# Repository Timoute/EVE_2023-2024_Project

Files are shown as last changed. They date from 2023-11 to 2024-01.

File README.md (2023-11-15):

# Cahier des charges Gants 

## Objectif General
- Contrôle de robot
    - Mouvement
        - Mecanique
        - " peau artificiel "
    - Contraction Muscle
    - Orientation de la main
    - Contact des doigts
    - Haptic feedback (potentiometre)
## Pour qui ?
Doit pouvoir être utilisé par une personne sans handicape 

## Présentation du projet
Objectif général : Contrôler un robot avec un gant 
Objectifs spécifiques :
- Feedback
- Réception des signaux musculaires 
- Retour sur l’orientation - position du robot
- Piloter la main avec le gant ou avoir des actions spécifiques pour chaque mouvement fait avec le gant. 
    
## Description des besoin
Besoins fonctionnels :  
- feedback réception des signaux musculaires 
- retour sur l’orientation 
- position du robot 
- piloter la main avec le gant ou avoir des actions spécifiques pour chaque mouvement fait avec le gant. 
                        
Besoins non fonctionnels : ergonomie, sécurité 

## Contraintes
Contraintes techniques : ROS, Python, C, Arduino IDE, Velostat

Contraintes budgétaires : 

Contraintes temporelles : Janvier 2024.

## Spécifications détaillées
Architecture : décrivez la structure générale du projet.

Interfaces : Cube IDE, VS Code, ROS

Bases de données : décrivez les besoins en matière de stockage et de gestion des données.

## Critères d'acceptation
- Énumérez les conditions qui doivent être remplies pour que le projet soit considéré comme réussi :
- Avoir un gant fonctionnel et ergonomique
- Acquérir des signaux en fonctions de différentes actions de la main ( mouvement des doigts, contraction des muscles, orientation de la main…)
- Avoir une communication stable 

## Liste des capteurs
- Electromyogram :
    - https://www.gotronic.fr/art-capteur-emg-sen0240-27861.htm
    - https://eu.robotshop.com/fr/products/electromyography-emg-sensor
    - https://www.mouser.fr/ProductDetail/SparkFun/DEV-18425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
    - https://www.gotronic.fr/art-capteur-pour-muscle-myoware-2-0-36900.htm
- Gyroscope, accélerometre, magnétomètre, capteur d'orientation : sans PCB : https://www.mouser.fr/ProductDetail/TDK-InvenSense/MPU-9250?qs=u4fy%2FsgLU9OhGjFkQSZssA%3D%3D
  avec PCB : https://www.amazon.fr/9250-Module-Acc%C3%A9l%C3%A9rom%C3%A8tre-Gyroscope-magn%C3%A9tom%C3%A8tre-Raspberry/dp/B01M74J70A
- Velostat(artificial skin): to capture pressure, twist
- Pressure sensor: to capture the contact between two fingers: https://www.gotronic.fr/art-capteur-de-force-fsr01-11552.htm
- Potentiometer: to capture finger bending
    Potentiometre linéaire x5: https://www.mouser.fr/ProductDetail/Bourns/PTA2043-2015CIB203?qs=AQlKX63v8RsiU3Md8%2FQpDw%3D%3D

- INSPIRATION
- https://www.youtube.com/watch?v=xNSRmXKSI_4
- https://fr.farnell.com/adafruit-industries/1361/accessory-type-conductive-sheet/dp/2419170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|pcrid||plid||kword||match||slid||product|2419170|pgrid||ptaid||&CMP=KNC-GFR-GEN-SHOPPING-Catch-All-Geo-Split-Control-12-July-23&gross_price=true

  video : https://www.youtube.com/watch?v=nHVNF83Se9k

Pourquoi celui la ? 

Pour mettre une image : 
name

https://github.com/someone-eng/LeapMotion-remote-controlling-robot-hand

MYOWare
https://cdn.sparkfun.com/assets/learn_tutorials/1/9/5/6/MyoWare_v2_QuickStartGuide.pdf
https://github.com/sparkfun/SparkFun_MyoWare_Code_Examples
https://microcontrollerslab.com/force-sensor-fsr-arduino-tutorial/

## To Order
- STM32 : https://www.mouser.fr/ProductDetail/STMicroelectronics/STM32G474RET6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

### RS Component

### Wurth Elektronik

### Mouser Electronics

# Base de Données pour IA
Fait avec le Leap Motion
https://www.kaggle.com/datasets/gti-upm/leapgestrecog/

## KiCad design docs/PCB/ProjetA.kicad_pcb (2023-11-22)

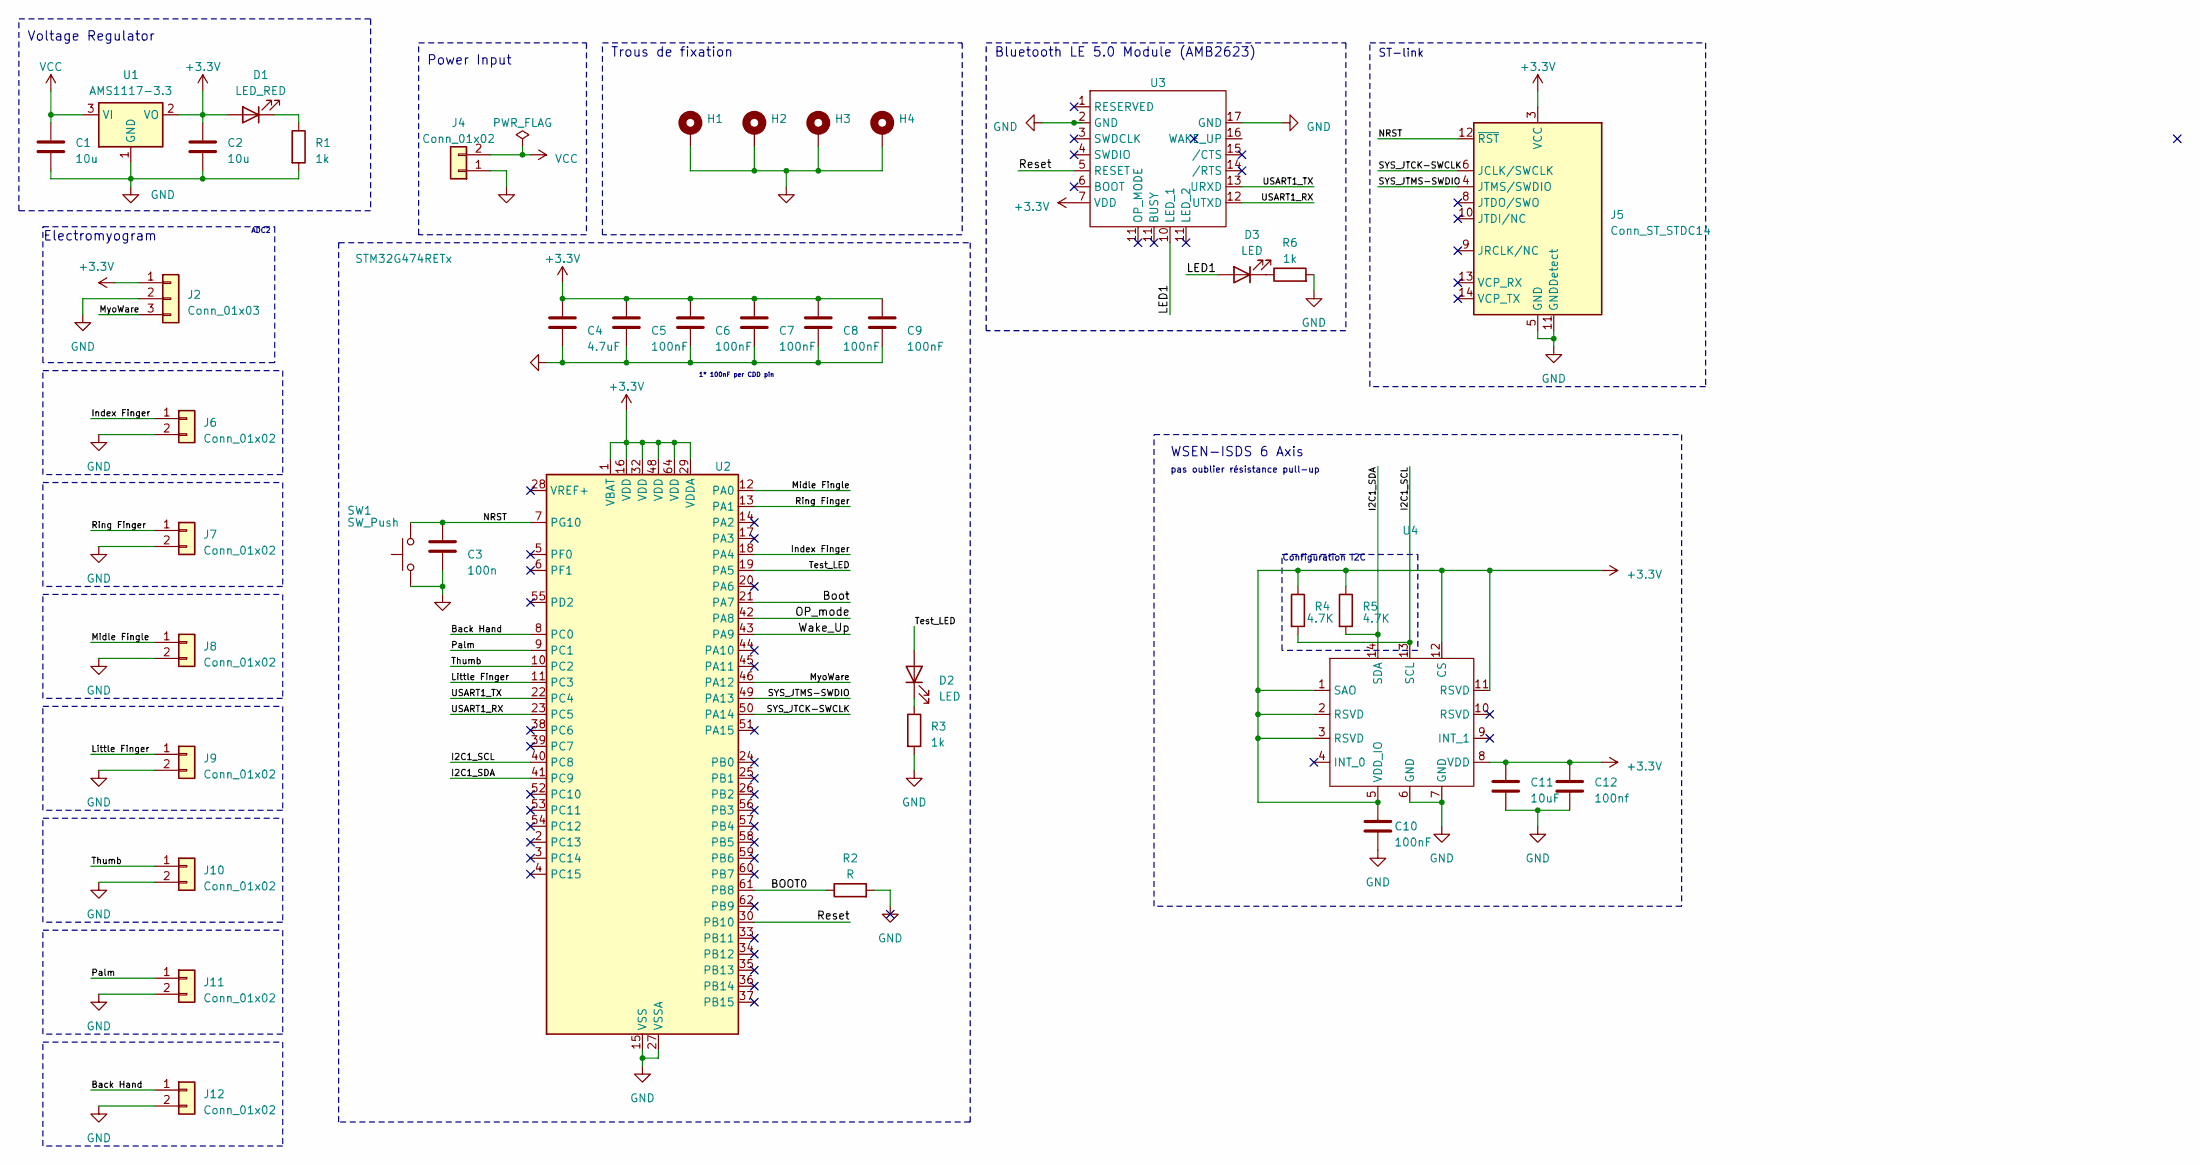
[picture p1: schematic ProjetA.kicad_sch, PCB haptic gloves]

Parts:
C1, C2: 10u; C_0603_1608Metric_Pad1.08x0.95mm_HandSolder
C3: 100n; C_0603_1608Metric_Pad1.08x0.95mm_HandSolder
C4: 4.7uF; C_0603_1608Metric_Pad1.08x0.95mm_HandSolder
C5, C6, C7, C8, C9, C10: 100nF; C_0603_1608Metric_Pad1.08x0.95mm_HandSolder
C11: 10uF; C_0603_1608Metric_Pad1.08x0.95mm_HandSolder
C12: 100nf; C_0603_1608Metric_Pad1.08x0.95mm_HandSolder
D1: LED_RED; LED_0603_1608Metric_Pad1.05x0.95mm_HandSolder
D2, D3: LED; LED_0603_1608Metric_Pad1.05x0.95mm_HandSolder
H1, H2, H3, H4: MountingHole_Pad; MountingHole_2.7mm_Pad_Via
J2: Conn_01x03; JST_XH_B3B-XH-A_1x03_P2.50mm_Vertical
J4: Conn_01x02; JST_XH_B2B-XH-A_1x02_P2.50mm_Vertical
J5: Conn_ST_STDC14; PinHeader_2x07_P1.27mm_Vertical_SMD
J6, J7, J8, J9, J10, J11, J12: Conn_01x02; JST_XH_S2B-XH-A_1x02_P2.50mm_Horizontal
R1, R3, R6: 1k; R_1206_3216Metric_Pad1.30x1.75mm_HandSolder
R2: R; R_1206_3216Metric_Pad1.30x1.75mm_HandSolder
R4, R5: 4.7K; R_1206_3216Metric_Pad1.30x1.75mm_HandSolder
SW1: SW_Push; SW_SPST_B3U-1000P
U1: AMS1117-3.3; SOT-223-3_TabPin2
U2: STM32G474RETx; LQFP-64_10x10mm_P0.5mm
U3: Proteus-II (Bluetooth)
U4: WSEN-ISDS 6 Axis IMU

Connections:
+3.3V: C2.2, C4.1, C5.1, C6.1, C7.1, C8.1, C9.1, C10.1, C11.1, C12.1, D1.2 (A), J2.1, J5.3 (VCC), R4.1, R5.1, U1.2 (VO), U2.1 (VBAT), U2.16 (VDD), U2.29 (VDDA), U2.32 (VDD), U2.48 (VDD), U2.64 (VDD), U3.7 (VDD), U4.1 (SAO), U4.2 (RSVD), U4.3 (RSVD), U4.5 (VDD_IO), U4.8 (VDD), U4.11 (RSVD), U4.12 (CS)
/BOOT0: R2.1, U2.61 (PB8)
/Back Hand: J12.1, U2.8 (PC0)
/Boot: U2.21 (PA7)
/I2C1_SCL: R4.2, U2.40 (PC8), U4.13 (SCL)
/I2C1_SDA: R5.2, U2.41 (PC9), U4.14 (SDA)
/Index Finger: J6.1, U2.18 (PA4)
/LED1: D3.2 (A), U3.10 (LED_1)
/Little Finger: J9.1, U2.11 (PC3)
/Midle Fingle: J8.1, U2.12 (PA0)
/MyoWare: J2.3, U2.46 (PA12)
/NRST: C3.1, J5.12 (~RST), SW1.2, U2.7 (PG10)
/OP_mode: U2.42 (PA8)
/Palm: J11.1, U2.9 (PC1)
/Reset: U2.30 (PB10), U3.5 (RESET)
/Ring Finger: J7.1, U2.13 (PA1)
/SYS_JTCK-SWCLK: J5.6 (JCLK/SWCLK), U2.50 (PA14)
/SYS_JTMS-SWDIO: J5.4 (JTMS/SWDIO), U2.49 (PA13)
/Test_LED: D2.2 (A), U2.19 (PA5)
/Thumb: J10.1, U2.10 (PC2)
/USART1_RX: U2.23 (PC5), U3.12 (UTXD)
/USART1_TX: U2.22 (PC4), U3.13 (URXD)
/Wake_Up: U2.43 (PA9)
GND: C1.1, C2.1, C3.2, C4.2, C5.2, C6.2, C7.2, C8.2, C9.2, C10.2, C11.2, C12.2, H1.1, H2.1, H3.1, H4.1, J2.2, J4.1, J5.5 (GND), J5.7 (GND), J5.11 (GNDDetect), J6.2, J7.2, J8.2, J9.2, J10.2, J11.2, J12.2, R1.2, R2.2, R3.2, R6.2, SW1.1, U1.1 (GND), U2.15 (VSS), U2.27 (VSSA), U2.31 (VSS), U2.47 (VSS), U2.63 (VSS), U3.2 (GND), U3.17 (GND), U4.6 (GND), U4.7 (GND)
unnamed: D1.1 (K), R1.1
unnamed: D2.1 (K), R3.1
unnamed: D3.1 (K), R6.1
VCC: C1.2, J4.2, U1.3 (VI)

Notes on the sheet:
Voltage Regulator
1* 100nF per CDD pin
Configuration I2C
Trous de fixation
ST-link
pas oublier résistance pull-up
ADC2
WSEN-ISDS 6 Axis
Bluetooth LE 5.0 Module (AMB2623)
Electromyogram
Power Input

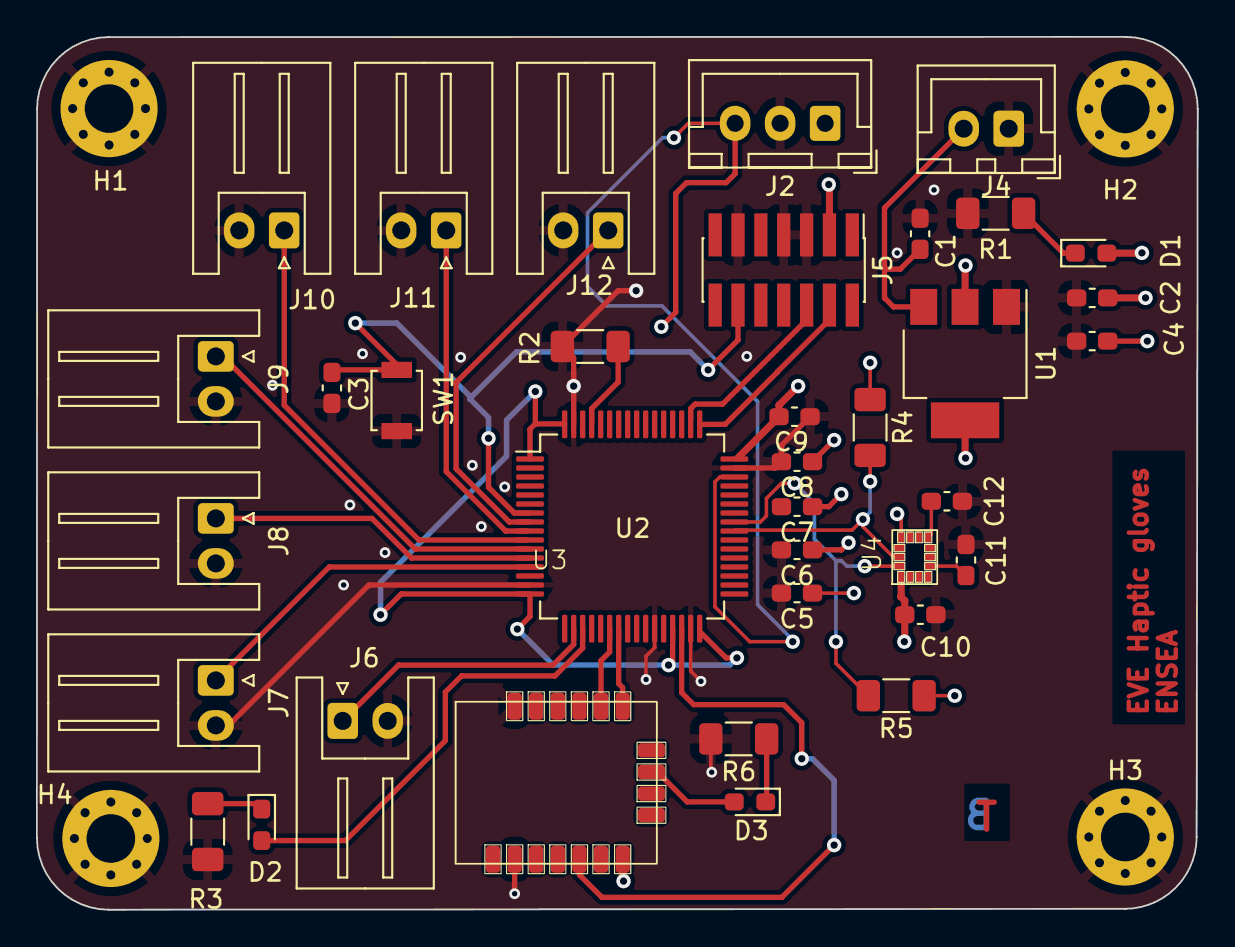
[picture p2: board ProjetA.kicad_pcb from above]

Board: 4 copper layers, 64.5 x 48.5 mm, 40 parts (0 on the bottom side), 25 nets.

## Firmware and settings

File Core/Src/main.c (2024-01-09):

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
/* Includes ------------------------------------------------------------------*/
#include "main.h"

/* USER CODE BEGIN Includes */
#include "mpu6050.h"
#include "string.h"
#include "stm32g4xx_hal.h"

/* USER CODE END Includes */

I2C_HandleTypeDef hi2c1;
I2C_HandleTypeDef hi2c2;

UART_HandleTypeDef hlpuart1;
UART_HandleTypeDef huart4;

/* USER CODE BEGIN PV */
uint8_t TX_Buffer[] = "A" ; // DATA to send
uint8_t uartTxBuffer[32];
MPU6050_t MPU6050;
#define ADDRESS_WRITE   0x52
#define ADDRESS_READ    0x53
#define MPU6050_I2C_ADDR 0x69

/* USER CODE END PV */

void SystemClock_Config(void);
static void MX_GPIO_Init(void);
static void MX_LPUART1_UART_Init(void);
static void MX_I2C1_Init(void);
static void MX_UART4_Init(void);
static void MX_I2C2_Init(void);
/**
  * @brief  The application entry point.
  * @retval int
  */
int main(void)
{
  /* USER CODE BEGIN 1 */

//	GPIO_InitTypeDef GPIO_InitStruct;
//
//	// Configurer la broche comme une entrée avec résistance de pull-up
//	GPIO_InitStruct.Pin = GPIO_PIN_0;  // Exemple : utilisez le numéro de broche approprié
//	GPIO_InitStruct.Mode = GPIO_MODE_IT_RISING;  // Mode d'interruption déclenché sur front montant
//	GPIO_InitStruct.Pull = GPIO_PULLUP;  // Résistance de tirage pull-up
//	HAL_GPIO_Init(GPIOA, &GPIO_InitStruct);  // Initialisez la broche avec la configuration
//
//	// Configurer la priorité de l'interruption
//	HAL_NVIC_SetPriority(EXTI0_IRQn, 0, 0);  // Epriorité de l'interruption
//	HAL_NVIC_EnableIRQ(EXTI0_IRQn);  // interruption pour la broche EXTI0
//

	uint8_t   return_value;
	uint8_t buf[12];
	int sizePrint,sizePrint0,sizePrint1,sizePrint2,sizePrint3,sizePrint4,sizePrint5,sizePrint6,sizePrint7,donnee;
	HAL_StatusTypeDef erreur_transmit,erreur_master_receive;
	unsigned char UcData[8]={0,0,0,0,0,0,0,0};
	uint8_t received_data[16]; // Pour stocker les 5 octets reçus
	HAL_StatusTypeDef status;
  /* USER CODE END 1 */

  /* MCU Configuration--------------------------------------------------------*/

  /* Reset of all peripherals, Initializes the Flash interface and the Systick. */
  HAL_Init();

  /* Configure the system clock */
  SystemClock_Config();

  /* Initialize all configured peripherals */
  MX_GPIO_Init();
  MX_LPUART1_UART_Init();
  MX_I2C1_Init();
  MX_UART4_Init();
  MX_I2C2_Init();
  MPU6050_Init(&hi2c2);
  /* USER CODE BEGIN 2 */

//  HAL_I2C_Master_Transmit_IT(&hi2c1,20,TX_Buffer,1); //Sending in Interrupt mode
  HAL_Delay(100);
  sizePrint = snprintf(uartTxBuffer, 32, "Starting\r\n");
  HAL_UART_Transmit(&hlpuart1, uartTxBuffer, sizePrint, 100);




  /* USER CODE END 2 */

  /* Infinite loop */
  /* USER CODE BEGIN WHILE */
  while (1)
  {//memset(received_data, 0, 5);

	  /*read_VL53L1X();*/
	  HAL_Delay (1000);
	  MPU6050_Read_All(&hi2c2, &MPU6050);
	  HAL_Delay (300);
	  char uartBufferAccel[100];
	  char uartBufferGyro[100];
	  char uartBufferTemp[100];

	  /*snprintf(uartBuffer, sizeof(uartBuffer), "Ax: %f\n"
	                                   "Ay: %f\n"
	                                   "Az: %f\n"
	  				 	 	 	 	   "Temperature: %f\n"
	                                   "Gx: %f\n"
	                                   "Gy: %f\n"
	                                   "Gz: %f\n"
	                                  , MPU6050.Ax, MPU6050.Ay, MPU6050.Az, MPU6050.Temperature, MPU6050.Gx, MPU6050.Gy, MPU6050.Gz);
	  HAL_UART_Transmit(&hlpuart1, (uint8_t *)uartBuffer, strlen(uartBuffer), HAL_MAX_DELAY);*/

	  MPU6050_Read_Accel(&hi2c2, &MPU6050);
	  snprintf(uartBufferAccel, sizeof(uartBufferAccel),"Ax: %f\r\nAy: %f\r\nAz: %f\r\n",MPU6050.Ax, MPU6050.Ay, MPU6050.Az);
	  HAL_UART_Transmit(&hlpuart1, (uint8_t *)uartBufferAccel, strlen(uartBufferAccel), HAL_MAX_DELAY);
	  HAL_Delay (200);

	  MPU6050_Read_Gyro(&hi2c2, &MPU6050);
	  snprintf(uartBufferGyro, sizeof(uartBufferGyro), "Gx: %f\r\nGy: %f\r\nGz: %f\r\n",MPU6050.Gx, MPU6050.Gy, MPU6050.Gz);
	  HAL_UART_Transmit(&hlpuart1, (uint8_t *)uartBufferGyro, strlen(uartBufferGyro), HAL_MAX_DELAY);
	  HAL_Delay (200);

	  MPU6050_Read_Temp(&hi2c2, &MPU6050);
	  snprintf(uartBufferTemp, sizeof(uartBufferTemp),"Temperature: %f\r\n",MPU6050.Temperature);
	  HAL_UART_Transmit(&hlpuart1, (uint8_t *)uartBufferTemp, strlen(uartBufferTemp), HAL_MAX_DELAY);
	  HAL_Delay (200);

	  MPU6050_Read_All(&hi2c2, &MPU6050);
	  snprintf(uartBufferTemp, sizeof(uartBufferTemp),"Pitch: %f\r\nRoll: %f\r\n",MPU6050.KalmanAngleY,MPU6050.KalmanAngleX);
	  HAL_UART_Transmit(&hlpuart1, (uint8_t *)uartBufferTemp, strlen(uartBufferTemp), HAL_MAX_DELAY);
	  HAL_Delay (200);



	  calculateVelocities(&MPU6050);
	  char uartBufferVelocities[100];
	  snprintf(uartBufferVelocities, sizeof(uartBufferVelocities), "Vx: %f\r\nVy: %f\r\nVz: %f\r\n", velocityX, velocityY, velocityZ);
	  HAL_UART_Transmit(&hlpuart1, (uint8_t *)uartBufferVelocities, strlen(uartBufferVelocities), HAL_MAX_DELAY);
	  HAL_Delay(200);







	  /*return_value = HAL_I2C_IsDeviceReady(&hi2c1, 0x52<<1, 1, 100);

	  const char *message;
	  if (return_value == 1)
	  {
	      message = "Le périphérique est prêt \r\n";
	  }
	  else
	  {
	      message = "Le périphérique n'est pas prêt \r\n";
	  }
	  sizePrint = snprintf(uartTxBuffer, 32, "Return value : %d\r\n", return_value);
	  HAL_UART_Transmit(&hlpuart1, uartTxBuffer, sizePrint, 100);

	  HAL_UART_Transmit(&hlpuart1, (uint8_t *)message, strlen(message), 100);
	  /*return_value = HAL_I2C_IsDeviceReady(&hi2c1, 0x52<<1, 1, 100);
	  sizePrint = snprintf(uartTxBuffer, 32, "Return value : %d\r\n", return_value);
	  HAL_UART_Transmit(&hlpuart1, uartTxBuffer, sizePrint, 100);*/

	  HAL_Delay(500);

	  /*// Démarrer la communication I2C
	  buf[0]=0x00;
	  status = HAL_I2C_Master_Transmit(&hi2c1, ADDRESS_READ << 1,buf, 1, HAL_MAX_DELAY);
	  if (status != HAL_OK) {// Gestion d'erreur
		  erreur_transmit=snprintf(uartTxBuffer, 32, "Erreur Transmit: %d\r\n",status);
		  HAL_UART_Transmit(&hlpuart1, uartTxBuffer, erreur_transmit, 100);


	  }

	  // Envoyer l'adresse du périphérique en lecture
	  status = HAL_I2C_Master_Receive(&hi2c1, (ADDRESS_READ << 1), received_data, sizeof(received_data), HAL_MAX_DELAY);
	  if (status != HAL_OK) {
	      // Gestion d'erreur
		  erreur_master_receive=snprintf(uartTxBuffer, 32, "Erreur Master_Receive: %d\r\n",status);
		  HAL_UART_Transmit(&hlpuart1, uartTxBuffer, erreur_master_receive, 100);
	  }
	  for (int i=0;i<16;i++) {
	      sizePrint = snprintf(uartTxBuffer, 32, "Element %d : %d\r\n", i, received_data[i]);
	      HAL_UART_Transmit(&hlpuart1, uartTxBuffer, sizePrint, 100);
	  }


	  HAL_Delay(1000);*/

	  /*for (int i=0;i<5;i++) {
		  received_data[i]=0;
	  }*/






	  /*HAL_I2C_Mem_Read(&hi2c1, 0x52<<1, 0x00,1,&UcData[0],  2, 100);
	  HAL_I2C_Mem_Read(&hi2c1, 0x52<<1, 0x00,1,&UcData[1],  2, 100);
	  HAL_I2C_Mem_Read(&hi2c1, 0x52<<1, 0x00,1,&UcData[2],  2, 100);
	  HAL_I2C_Mem_Read(&hi2c1, 0x52<<1, 0x00,1,&UcData[3],  2, 100);

	  HAL_I2C_Mem_Read(&hi2c1, 0x53<<1, 0x00,1,&UcData[4],  2, 100);
	  HAL_I2C_Mem_Read(&hi2c1, 0x53<<1, 0x00,1,&UcData[5],  2, 100);
	  HAL_I2C_Mem_Read(&hi2c1, 0x53<<1, 0x00,1,&UcData[6],  2, 100);
	  HAL_I2C_Mem_Read(&hi2c1, 0x53<<1, 0x00,1,&UcData[7],  2, 100);

	  sizePrint0 = snprintf(uartTxBuffer, 32, "Bit 0 : %d\r\n", UcData[0]);
	  HAL_UART_Transmit(&hlpuart1, uartTxBuffer, sizePrint0, 100);
	  sizePrint1 = snprintf(uartTxBuffer, 32, "Bit 1 : %d\r\n", UcData[1]);
	  HAL_UART_Transmit(&hlpuart1, uartTxBuffer, sizePrint1, 100);
	  sizePrint2 = snprintf(uartTxBuffer, 32, "Bit 2 : %d\r\n", UcData[2]);
	  HAL_UART_Transmit(&hlpuart1, uartTxBuffer, sizePrint2, 100);
	  sizePrint3 = snprintf(uartTxBuffer, 32, "Bit 3 : %d\r\n", UcData[3]);
	  HAL_UART_Transmit(&hlpuart1, uartTxBuffer, sizePrint3, 100);
	  sizePrint4 = snprintf(uartTxBuffer, 32, "Bit 4 : %d\r\n", UcData[4]);
	  HAL_UART_Transmit(&hlpuart1, uartTxBuffer, sizePrint4, 100);
	  sizePrint5 = snprintf(uartTxBuffer, 32, "Bit 5 : %d\r\n", UcData[5]);
	  HAL_UART_Transmit(&hlpuart1, uartTxBuffer, sizePrint5, 100);
	  sizePrint6 = snprintf(uartTxBuffer, 32, "Bit 6 : %d\r\n", UcData[6]);
	  HAL_UART_Transmit(&hlpuart1, uartTxBuffer, sizePrint6, 100);
	  sizePrint7 = snprintf(uartTxBuffer, 32, "Bit 7 : %d\r\n\n", UcData[7]);
	  HAL_UART_Transmit(&hlpuart1, uartTxBuffer, sizePrint7, 100);
	  HAL_Delay(1000);*/

	  /*strcpy((char*)buf,"Hello\r\n");
	  HAL_UART_Transmit(&hlpuart1,buf,strlen((char*)buf),HAL_MAX_DELAY);*/
	  HAL_Delay(500);

    /* USER CODE END WHILE */

    /* USER CODE BEGIN 3 */
  }
    /* USER CODE END WHILE */

    /* USER CODE BEGIN 3 */
	    }


    /* USER CODE BEGIN 3 */

void ReadMPU6050Data(void) {
	uint8_t buffer[6];
	int sizePrint;
	uint8_t uartTxBuffer[32];
	uint8_t received_data[16]; // Pour stocker les 5 octets reçus
	uint8_t buf[12];


    // Envoyer la commande de début de communication au MPU-60X0
	buf[0]=0x00;
    HAL_I2C_Master_Transmit(&hi2c2, MPU6050_I2C_ADDR << 1, buf, 1, HAL_MAX_DELAY);
    // Lire les données du MPU-60X0
    HAL_I2C_Master_Receive(&hi2c2, MPU6050_I2C_ADDR, buffer, 6, HAL_MAX_DELAY);
	for (int i=0;i<sizeof(buffer);i++) {
	    sizePrint = snprintf(uartTxBuffer, 32, "Element gyro %d : %d\r\n", i, buffer[i]);
	    HAL_UART_Transmit(&hlpuart1, uartTxBuffer, sizePrint, 100);

    // Maintenant, le buffer contient les données lues du MPU-60X0
	}
}
void read_VL53L1X(void){
	uint8_t   return_value;
	uint8_t buf[12];
	int sizePrint,sizePrint0,sizePrint1,sizePrint2,sizePrint3,sizePrint4,sizePrint5,sizePrint6,sizePrint7,donnee;
	HAL_StatusTypeDef erreur_transmit,erreur_master_receive;
	unsigned char UcData[8]={0,0,0,0,0,0,0,0};
	uint8_t received_data[16]; // Pour stocker les 5 octets reçus

	HAL_StatusTypeDef status;
	uint8_t TX_Buffer[] = "A" ; // DATA to send
	uint8_t uartTxBuffer[32];
	return_value = HAL_I2C_IsDeviceReady(&hi2c1, 0x52<<1, 1, 100);

	const char *message;
	if (return_value == 1)
	{
	    message = "Le tof est prêt \r\n";
	}
	else
	{
	    message = "Le tof n'est pas prêt \r\n";
	}
	sizePrint = snprintf(uartTxBuffer, 32, "Return value : %d\r\n", return_value);
	HAL_UART_Transmit(&hlpuart1, uartTxBuffer, sizePrint, 100);
	HAL_UART_Transmit(&hlpuart1, (uint8_t *)message, strlen(message), 100);
	return_value = HAL_I2C_IsDeviceReady(&hi2c1, 0x52<<1, 1, 100);
	sizePrint = snprintf(uartTxBuffer, 32, "Return value : %d\r\n", return_value);
	HAL_UART_Transmit(&hlpuart1, uartTxBuffer, sizePrint, 100);

	HAL_Delay(500);

	  // Démarrer la communication I2C
	buf[0]=0x00;
	status = HAL_I2C_Master_Transmit(&hi2c1, ADDRESS_READ << 1,buf, 1, HAL_MAX_DELAY);
	if (status != HAL_OK) {// Gestion d'erreur
		erreur_transmit=snprintf(uartTxBuffer, 32, "Erreur Transmit: %d\r\n",status);
		HAL_UART_Transmit(&hlpuart1, uartTxBuffer, erreur_transmit, 100);


	}

	  // Envoyer l'adresse du périphérique en lecture
	status = HAL_I2C_Master_Receive(&hi2c1, (ADDRESS_READ << 1), received_data, sizeof(received_data), HAL_MAX_DELAY);
	if (status != HAL_OK) {
	    // Gestion d'erreur
		erreur_master_receive=snprintf(uartTxBuffer, 32, "Erreur Master_Receive: %d\r\n",status);
		HAL_UART_Transmit(&hlpuart1, uartTxBuffer, erreur_master_receive, 100);
	}
	for (int i=0;i<16;i++) {
	    sizePrint = snprintf(uartTxBuffer, 32, "Element tof %d : %d\r\n", i, received_data[i]);
	    HAL_UART_Transmit(&hlpuart1, uartTxBuffer, sizePrint, 100);
	}


	HAL_Delay(1000);
}
  /* USER CODE END 3 */


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


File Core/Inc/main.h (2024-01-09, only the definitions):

#define B1_Pin GPIO_PIN_13
#define B1_GPIO_Port GPIOC
#define B1_EXTI_IRQn EXTI15_10_IRQn
#define INT1_Pin GPIO_PIN_0
#define INT1_GPIO_Port GPIOC
#define INT1_EXTI_IRQn EXTI0_IRQn
#define INT2_Pin GPIO_PIN_1
#define INT2_GPIO_Port GPIOC
#define INT2_EXTI_IRQn EXTI1_IRQn
#define LPUART1_TX_Pin GPIO_PIN_2
#define LPUART1_TX_GPIO_Port GPIOA
#define LD2_Pin GPIO_PIN_5
#define LD2_GPIO_Port GPIOA
#define T_SWDIO_Pin GPIO_PIN_13
#define T_SWDIO_GPIO_Port GPIOA
#define T_SWCLK_Pin GPIO_PIN_14
#define T_SWCLK_GPIO_Port GPIOA
#define T_SWO_Pin GPIO_PIN_3
#define T_SWO_GPIO_Port GPIOB

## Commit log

2023-11-22 Create KiCad
    KiCad Files
2023-11-22 KiCad Files
    [ProjetA.kicad_pcb, ProjetA.kicad_sch]

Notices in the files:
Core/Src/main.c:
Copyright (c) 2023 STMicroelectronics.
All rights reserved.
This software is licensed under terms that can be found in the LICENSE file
